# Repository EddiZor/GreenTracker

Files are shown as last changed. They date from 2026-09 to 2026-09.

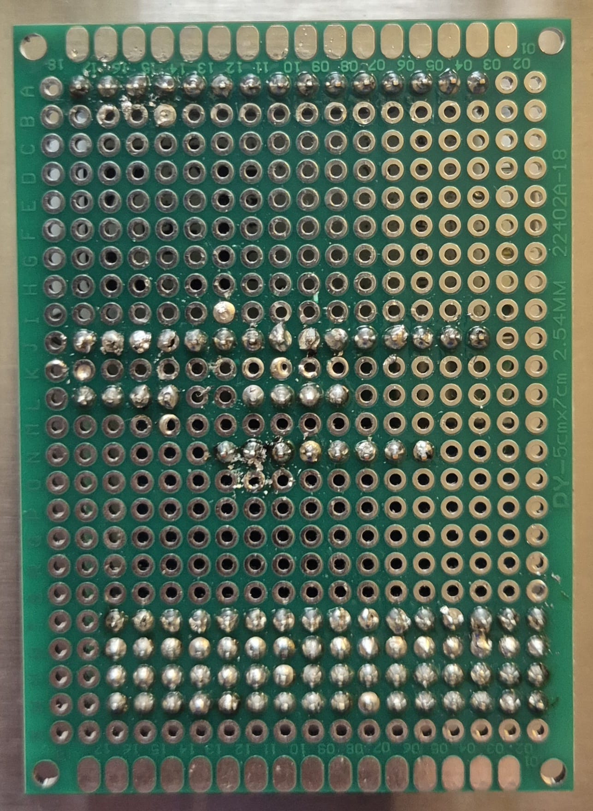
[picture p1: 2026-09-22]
images/002.jpeg

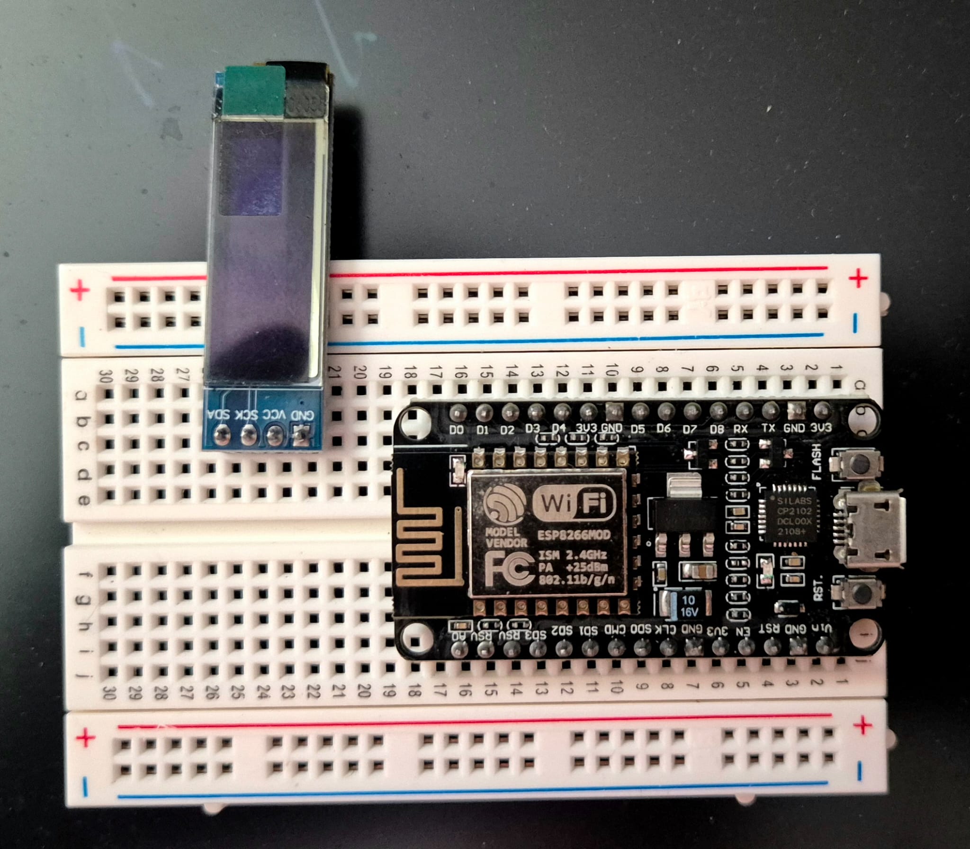
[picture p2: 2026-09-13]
WhatsApp Image 2026-09-13 at 14.21.58.jpeg

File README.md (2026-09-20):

# 🌿 GreenTracker v4.0

GreenTracker è un sistema IoT basato su ESP8266 (NodeMCU) progettato per monitorare l'umidità del suolo di un massimo di 16 piante contemporaneamente. 
La versione 4.0 trasforma il dispositivo in un server web autonomo, offrendo una dashboard in tempo reale accessibile da qualsiasi smartphone, oltre al rilevamento intelligente dei sensori e agli avvisi push.

## ✨ Novità della Versione 4.0
* **Web App Integrata:** Il NodeMCU genera nativamente una pagina web in HTML/CSS (Responsive & Dark Mode). Inserendo l'indirizzo IP del dispositivo nel browser dello smartphone, si ottiene una dashboard completa con i dati di tutti i sensori connessi.
* **Ritardo Intelligente (Smart Delay):** Creata una funzione dedicata (`attesaIntelligente`) per mantenere in ascolto il server web in background durante il carosello dei display OLED, azzerando i tempi di blocco.
* **Sistema Plug & Play:** Rileva automaticamente quali sensori sono fisicamente collegati ignorando le porte vuote e aggiornando dinamicamente i display e l'interfaccia web.
* **Notifiche Pushover:** Invia un alert push allo smartphone quando l'umidità di una specifica pianta scende sotto il 20% (con logica Anti-Spam integrata).

## 🛠️ Hardware Necessario
* 1x ESP8266 NodeMCU (ESP-12E)
* 1x Multiplexer Analogico 16 canali CD74HC4067 (Modello **HW-178**)
* 2x Display OLED 0.91" 128x32 (I2C)
* Fino a 16 Sensori di umidità del suolo capacitivi
* 2x Resistenze da 10 kOhm (da collegare in serie per ottenere 20 kOhm come pull-down)
* 1x Basetta Millefori 24x18

## 📖 Istruzioni di Assemblaggio
Per i dettagli su come saldare i componenti sulla millefori (ottimizzata per il modello HW-178) e la checklist dei collegamenti, consulta il file [ASSEMBLY.md](ASSEMBLY.md).

# 🌿 GreenTracker v3.0

GreenTracker è un sistema IoT basato su ESP8266 (NodeMCU) progettato per monitorare l'umidità del suolo di un massimo di 16 piante contemporaneamente. 
La versione 3.0 introduce il rilevamento intelligente dei sensori, avvisi push su smartphone e un layout hardware ottimizzato.

## ✨ Novità della Versione 3.0
* **Sistema Plug & Play:** Il sistema rileva automaticamente quali sensori sono fisicamente collegati (grazie a una resistenza di pull-down da 20kOhm) e ignora le porte vuote, aggiornando dinamicamente il carosello sui display OLED.
* **Notifiche Pushover:** Integrazione con l'API HTTPS di Pushover. Invia un alert sullo smartphone quando l'umidità di una specifica pianta scende sotto il 20%.
* **Logica Anti-Spam:** Il sistema memorizza lo stato degli allarmi inviati. Non invierà nuove notifiche per la stessa pianta finché l'umidità non tornerà sopra il 25%.
* **Self-Healing WiFi:** Inserita una routine di formattazione temporanea della memoria radio all'avvio per evitare conflitti di credenziali.

## 🛠️ Hardware Necessario
* 1x ESP8266 NodeMCU (ESP-12E)
* 1x Multiplexer Analogico 16 canali CD74HC4067 (Modello **HW-178**)
* 2x Display OLED 0.91" 128x32 (I2C)
* Fino a 16 Sensori di umidità del suolo capacitivi
* 1x Resistenza da 20 kOhm
* 1x Basetta Millefori 24x18

## 📖 Istruzioni di Assemblaggio
Per i dettagli su come saldare i componenti sulla millefori e la checklist dei collegamenti, consulta il file [ASSEMBLY.md](ASSEMBLY.md).

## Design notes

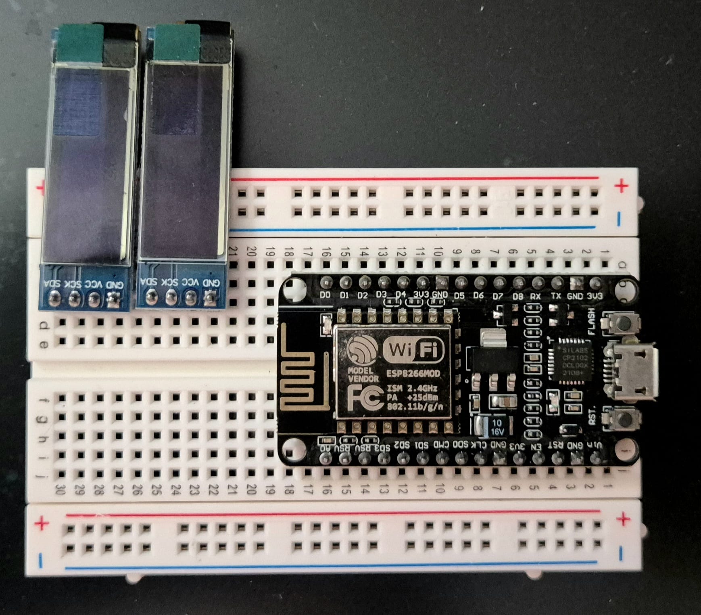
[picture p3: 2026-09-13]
WhatsApp Image 2026-09-13 at 14.21.58 b.jpeg

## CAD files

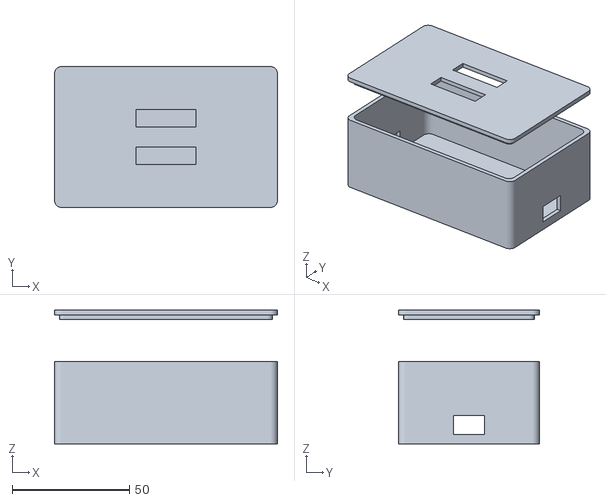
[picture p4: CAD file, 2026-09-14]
Case_3D/GreenTracker_Case.stl
95.0 x 60.0 x 57.0

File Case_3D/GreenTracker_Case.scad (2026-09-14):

// --- GreenTracker Case v1.0 ---

/* [Dimensioni Generali Scatola] */
lunghezza = 95;  // Spazio per NodeMCU e Multiplexer
larghezza = 60;
altezza = 35;
spessore_muro = 2;

/* [Tolleranze e Smussi] */
tolleranza_incastro = 0.4; // Tolleranza per la stampa 3D del coperchio
raggio_angoli = 3;         // Arrotondamento degli angoli esterni
$fn = 60;                  // Risoluzione curve

/* [Display OLED 0.91"] */
oled_finestra_l = 25.5; // Area visibile dello schermo
oled_finestra_h = 7.5;
distanza_tra_oled = 16; // Distanza dal centro di un display all'altro

/* [Connessioni] */
usb_l = 13;
usb_h = 8;
foro_cavi_l = 15;
foro_cavi_h = 8;

// --- MODULI BASE ---

module scatola_arrotondata(l, w, h, r) {
    hull() {
        translate([-l/2+r, -w/2+r, 0]) cylinder(r=r, h=h);
        translate([ l/2-r, -w/2+r, 0]) cylinder(r=r, h=h);
        translate([-l/2+r,  w/2-r, 0]) cylinder(r=r, h=h);
        translate([ l/2-r,  w/2-r, 0]) cylinder(r=r, h=h);
    }
}

module case_base() {
    difference() {
        // Corpo esterno
        scatola_arrotondata(lunghezza, larghezza, altezza, raggio_angoli);
        
        // Scavo interno
        translate([0, 0, spessore_muro])
            scatola_arrotondata(lunghezza - spessore_muro*2, larghezza - spessore_muro*2, altezza, raggio_angoli);
            
        // Foro USB (centrato su un lato corto)
        translate([lunghezza/2, 0, spessore_muro + usb_h/2 + 2])
            cube([spessore_muro*4, usb_l, usb_h], center=true);
            
        // Foro uscita cavi sensore/i (lato opposto)
        translate([-lunghezza/2, 0, spessore_muro + foro_cavi_h/2 + 2])
            cube([spessore_muro*4, foro_cavi_l, foro_cavi_h], center=true);
    }
}

module coperchio() {
    difference() {
        union() {
            // Piano del coperchio
            scatola_arrotondata(lunghezza, larghezza, spessore_muro, raggio_angoli);
            
            // Labbro di incastro interno
            translate([0, 0, -spessore_muro])
                scatola_arrotondata(
                    lunghezza - spessore_muro*2 - tolleranza_incastro, 
                    larghezza - spessore_muro*2 - tolleranza_incastro, 
                    spessore_muro, 
                    raggio_angoli - 1
                );
        }
        
        // Scavo per alleggerire il labbro interno
        translate([0, 0, -spessore_muro - 0.1])
            scatola_arrotondata(
                lunghezza - spessore_muro*4 - tolleranza_incastro, 
                larghezza - spessore_muro*4 - tolleranza_incastro, 
                spessore_muro + 0.2, 
                raggio_angoli - 2
            );

        // Finestra OLED 1 (Superiore) - Posizione Z corretta per trapassare il tetto
        translate([0, distanza_tra_oled/2, 0])
            cube([oled_finestra_l, oled_finestra_h, 20], center=true);
            
        // Finestra OLED 2 (Inferiore) - Posizione Z corretta per trapassare il tetto
        translate([0, -distanza_tra_oled/2, 0])
            cube([oled_finestra_l, oled_finestra_h, 20], center=true);
    }
}

// --- ASSEMBLAGGIO CON COLORI ---

// Base della scatola in grigio scuro
color([0.25, 0.25, 0.28]) 
    case_base();

// Coperchio in verde (sollevato di 20mm in vista esplosa)
color([0.2, 0.7, 0.3]) 
    translate([0, 0, altezza + 20]) 
        coperchio();

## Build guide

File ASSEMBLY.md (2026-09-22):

# 🛠️ Guida all'Assemblaggio GreenTracker

## 🗺️ Layout Millefori (Griglia 18x24 - Scala Reale 1:1)

Questo schema riproduce fedelmente la matrice di 18 colonne x 24 righe della scheda. Ogni simbolo rappresenta un singolo foro.
* `O` = Foro vuoto
* `N` = Pin del NodeMCU
* `[H]` = Connettori femmina (Header) per gli OLED
* `M` = Pin del Multiplexer (HW-178)
* `[S]`, `[V]`, `[G]` = Pettini inferiori Sensore, VCC, GND

```text
    1  2  3  4  5  6  7  8  9 10 11 12 13 14 15 16 17 18
  +----------------------------------------------------+
 1| O  N  N  N  N  N  N  N  N  N  N  N  N  N  N  N  O  O | <- NodeMCU (Top)
 2| O  |                                         |  O  O |
 3| O  |                                         |  O  O |
 4| O  |           N O D E   M C U               |  O  O |
 5| O  |          (USB a sinistra)               |  O  O |
 6| O  |                                         |  O  O |
 7| O  |                                         |  O  O |
 8| O  |                                         |  O  O |
 9| O  |                                         |  O  O |
10| O  N  N  N  N  N  N  N  N  N  N  N  N  N  N  N  O  O | <- NodeMCU (Bot)
11| O  O  O  O  O  O  O  O  O  O  O  O  O  O  O  O  O  O |
12| O  O  O  O  O [H][H][H][H] O [H][H][H][H] O  O  O  O | <- Prese OLED
13| O  O  O  O  O  O  O  O  O  O  O  O  O  O  O  O  O  O |
14| O  O  O  O  O  O  O  O  O  O  O  O  O  O  O  O  O  O |
15| O  O  O  O  O  M  M  M  M  M  M  M  M  O  O  O  O  O | <- MUX (Controllo)
16| O  O  O  O  O  |                    |  O  O  O  O  O |
17| O  O  O  O  O  |       HW-178       |  O  O  O  O  O |
18| O  O  O  O  O  |                    |  O  O  O  O  O |
19| O  O  O  O  O  |                    |  O  O  O  O  O |
20| O  M  M  M  M  M  M  M  M  M  M  M  M  M  M  M  M  O | <- MUX (Canali)
21| O  O  O  O  O  O  O  O  O  O  O  O  O  O  O  O  O  O |
22| O [S][S][S][S][S][S][S][S][S][S][S][S][S][S][S][S] O | <- 1. Pettine Segnali
23| O [V][V][V][V][V][V][V][V][V][V][V][V][V][V][V][V] O | <- 2. Pettine VCC 3.3V
24| O [G][G][G][G][G][G][G][G][G][G][G][G][G][G][G][G] O | <- 3. Pettine GND
  +----------------------------------------------------+
```

### 🪧 Legenda dei Pin (Da Sinistra a Destra)
* **NodeMCU Top (Riga 1):** A0, RSV, RSV, SD3, SD2, SD1, CMD, SD0, CLK, GND, 3V3, EN, RST, GND, Vin
* **NodeMCU Bot (Riga 10):** D0, D1, D2, D3, D4, 3V3, GND, D5, D6, D7, D8, RX, TX, GND, 3V3
* **MUX Controllo (Riga 15):** SIG, S3, S2, S1, S0, EN, VCC, GND
* **MUX Canali (Riga 20):** C15, C14, C13, C12, C11, C10, C9, C8, C7, C6, C5, C4, C3, C2, C1, C0

---

## 📋 Checklist Cablaggi e Saldature

**FASE 1: Blocco di Alimentazione (Pettini Inferiori)**
*Prepara le tre righe di pettini femmina sul fondo della scheda.*

- [ ] **Autostrada GND:** Unisci tutti i pin della riga inferiore (Riga 24) per creare il binario di Massa.
- [ ] Collega il binario GND a un pin **GND** del NodeMCU.
- [ ] Collega il binario GND al pin **GND** del Multiplexer (Riga 15, Colonna 13).
- [ ] Collega il binario GND al pin **EN** del Multiplexer (Riga 15, Colonna 11).
- [ ] Collega il binario GND ai due pin **GND** dei connettori OLED (es. ai secondi pin delle prese).
- [ ] **Autostrada VCC:** Unisci tutti i pin della riga centrale (Riga 23) per creare il binario 3.3V.
- [ ] Collega il binario VCC al pin **3V3** del NodeMCU.
- [ ] Collega il binario VCC al pin **VCC** del Multiplexer (Riga 15, Colonna 12).
- [ ] Collega il binario VCC ai due pin **VCC** dei connettori OLED.

**FASE 2: Cablaggi Display I2C (Prese Centrali sulla Riga 12)**
*Essendo i connettori posizionati perfettamente sotto i pin I2C del NodeMCU, le saldature saranno cortissime.*

- [ ] Connettore OLED 1 (SCL) -> Pin **D1** (NodeMCU, Colonna 3)
- [ ] Connettore OLED 1 (SDA) -> Pin **D2** (NodeMCU, Colonna 4)
- [ ] Connettore OLED 2 (SCL) -> Pin **D5** (NodeMCU, Colonna 9)
- [ ] Connettore OLED 2 (SDA) -> Pin **D6** (NodeMCU, Colonna 10)

**FASE 3: Logica Multiplexer e Plug & Play**
*Collega la fila da 8 pin del Multiplexer (Riga 15) ai rispettivi pin del NodeMCU.*

- [ ] Multiplexer **S0** (Col. 10) -> Pin **D3** (NodeMCU, Col. 5)
- [ ] Multiplexer **S1** (Col. 9) -> Pin **D4** (NodeMCU, Col. 6)
- [ ] Multiplexer **S2** (Col. 8) -> Pin **D7** (NodeMCU, Col. 11)
- [ ] Multiplexer **S3** (Col. 7) -> Pin **D8** (NodeMCU, Col. 12)
- [ ] Multiplexer **SIG** (Col. 6) -> Pin **A0** (NodeMCU, Col. 2 superiore)
- [ ] **Resistenza Plug & Play:** Salda DUE resistenze da 10k Ohm in serie (totale 20k Ohm) tra la pista di Segnale (A0 / SIG) e un punto connesso al **GND**.

**FASE 4: Segnali Sensori a Cascata (Righe 20-22)**
*Crea dei ponti verticali diritti di un paio di millimetri saltando la riga vuota (21), unendo i pin del Multiplexer (Riga 20) al pettine segnali sottostante (Riga 22).*

- [ ] Multiplexer **C15** -> Pettine Segnali Pin 1 (Estrema Sinistra, Colonna 2)
- [ ] Multiplexer da **C14** a **C1** -> Collega verticalmente ciascun pin al rispettivo foro sottostante (Colonne 3-16).
- [ ] Multiplexer **C0** -> Pettine Segnali Pin 16 (Estrema Destra, Colonna 17)

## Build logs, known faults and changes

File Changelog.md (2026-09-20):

### 4. File di Log delle Versioni (`CHANGELOG.md`)

```markdown
# Changelog
Tutte le modifiche rilevanti a questo progetto saranno documentate in questo file.

## [4.0.0] - 2026-09-20

### Aggiunto
- **Server Web Nativo:** Implementata la libreria `ESP8266WebServer` per ospitare una pagina HTML/CSS direttamente sulla memoria del NodeMCU.
- **Web App Dashboard:** Creata un'interfaccia utente responsive per smartphone (stile Dark Mode) che mostra in tempo reale i valori di umidità e segnala in rosso i sensori in allarme.
- **Supporto IP su Display:** Il secondo schermo OLED ora alterna la visualizzazione dello stato del WiFi con l'indirizzo IP locale, rendendo immediato l'accesso alla Web App.

### Modificato
- **Codifica Caratteri:** Aggiunto il tag `<meta charset='UTF-8'>` nell'HTML generato per interpretare correttamente gli emoji nei browser mobile.
- **Gestione del Timing:** Sostituiti i classici `delay()` nel loop principale con la nuova funzione custom `attesaIntelligente()`, che esegue un polling continuo di `server.handleClient()` garantendo l'assenza di lag durante la navigazione sulla Web App.

## [3.0.0] - 2026-09-19

### Aggiunto
- **Rilevamento Plug & Play:** Implementata logica per ignorare automaticamente le porte vuote del multiplexer.
- **Supporto Pushover:** Inserita libreria `ESP8266HTTPClient` per inviare notifiche push (HTTPS) allo smartphone.
- **Logica Anti-Spam:** Sistema di booleani per evitare invii ripetuti di allarmi sotto la soglia critica del 20%.
- **Layout Hardware HW-178:** Creata una mappatura dedicata per la basetta millefori 24x18.
- **Checklist Saldature:** Aggiunto un tracker in Markdown nel file ASSEMBLY.md.

### Modificato
- **Routine di connessione WiFi:** Aggiunto blocco `WiFi.mode(WIFI_STA); WiFi.disconnect();` nel setup per forzare il reset della memoria radio ed evitare loop di connessione.

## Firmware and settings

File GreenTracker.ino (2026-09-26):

/**
 * Progetto: GreenTracker
 * Versione: 5.1 (Fixed Serial Boot & Pushover HTTP)
 * Autore: SKYSIM PILOT
 */

#include <Arduino.h>
#include <U8g2lib.h>
#include <Wire.h>
#include <ESP8266WiFi.h>
#include <ESP8266HTTPClient.h>
#include <ESP8266WebServer.h>
#include <time.h> // Libreria per l'orario

// --- Credenziali WiFi ---
const char* ssid = "IL_TUO_WIFI";       
const char* password = "LA_TUA_PASSWORD";   

// --- Credenziali Pushover ---
const char* pushoverApiToken = "INSERISCI_QUI_IL_TOKEN_APP";
const char* pushoverUserKey = "INSERISCI_QUI_IL_USER_KEY";

ESP8266WebServer server(80);

const int pin_S0 = D3;
const int pin_S1 = D4;
const int pin_S2 = D7;
const int pin_S3 = D8;
const int pin_SIG = A0;

const int MAX_SENSORI = 16; 
int valoriSensori[16]; 
bool sensoreConnesso[16]; 
bool allarmeInviato[16]; 

const int valoreAriaSecca = 850; 
const int valoreAcqua = 350;

U8G2_SSD1306_128X32_UNIVISION_F_SW_I2C display1(U8G2_R0, D1, D2, U8X8_PIN_NONE);
U8G2_SSD1306_128X32_UNIVISION_F_SW_I2C display2(U8G2_R0, D5, D6, U8X8_PIN_NONE);

void attesaIntelligente(unsigned long ms) {
  unsigned long inizio = millis();
  while (millis() - inizio < ms) {
    server.handleClient(); 
    delay(10);
  }
}

int leggiCanaleMux(int canale) {
  digitalWrite(pin_S0, bitRead(canale, 0));
  digitalWrite(pin_S1, bitRead(canale, 1));
  digitalWrite(pin_S2, bitRead(canale, 2));
  digitalWrite(pin_S3, bitRead(canale, 3));
  delay(10); 
  return analogRead(pin_SIG);
}

// --- FUNZIONE: Genera la pagina HTML della Web App ---
void gestisciPaginaPrincipale() {
  time_t now = time(nullptr);
  struct tm* timeinfo = localtime(&now);
  String orarioAggiornamento = "Sincronizzazione in corso...";
  if (timeinfo->tm_year > 120) { 
    char timeString[10];
    sprintf(timeString, "%02d:%02d:%02d", timeinfo->tm_hour, timeinfo->tm_min, timeinfo->tm_sec);
    orarioAggiornamento = String(timeString);
  }

  String html = "<!DOCTYPE html><html><head>";
  html += "<meta charset='UTF-8'>";
  html += "<meta name='viewport' content='width=device-width, initial-scale=1.0, user-scalable=no'>";
  html += "<meta name='apple-mobile-web-app-capable' content='yes'>";
  html += "<meta http-equiv='refresh' content='30'>"; // AUTO-REFRESH ogni 30 secondi
  html += "<title>GreenTracker Live</title>";
  html += "<style>";
  html += "body { font-family: 'Segoe UI', sans-serif; background-color: #121212; color: #fff; margin: 0; padding: 15px; text-align: center; }";
  html += "h1 { color: #4CAF50; font-size: 1.8em; margin-bottom: 10px; }";
  html += ".card { background-color: #1e1e1e; border-radius: 10px; padding: 15px; margin: 15px auto; max-width: 400px; box-shadow: 0 4px 8px rgba(0,0,0,0.4); text-align: left; }";
  html += ".card-header { display: flex; justify-content: space-between; align-items: center; margin-bottom: 8px; }";
  html += ".card-title { font-size: 1.1em; font-weight: bold; color: #eee; }";
  html += ".card-value { font-size: 1.3em; font-weight: bold; }";
  html += ".progress-bg { background-color: #333; border-radius: 5px; height: 10px; width: 100%; overflow: hidden; }";
  html += ".progress-bar { height: 100%; border-radius: 5px; transition: width 0.5s; }";
  html += ".bg-green { background-color: #4CAF50; color: #4CAF50; }";
  html += ".bg-yellow { background-color: #FFC107; color: #FFC107; }";
  html += ".bg-red { background-color: #F44336; color: #F44336; }";
  html += ".card-luce { border-left: 4px solid #FFC107; }";
  html += ".card-pianta { border-left: 4px solid #4CAF50; }";
  html += ".footer { color: #888; font-size: 0.85em; margin-top: 30px; line-height: 1.5; }";
  html += "</style></head><body>";
  
  html += "<h1>🌿 GreenTracker</h1>";
  
  bool almenoUnSensore = false;
  
  for (int i = 0; i < 15; i++) {
    if (sensoreConnesso[i]) {
      almenoUnSensore = true;
      int umidita = valoriSensori[i];
      
      String coloreClasse = "bg-green";
      if (umidita <= 20) coloreClasse = "bg-red";
      else if (umidita <= 40) coloreClasse = "bg-yellow";
      
      html += "<div class='card card-pianta'>";
      html += "<div class='card-header'>";
      html += "<span class='card-title'>🌱 Sensore " + String(i + 1) + " (C" + String(i) + ")</span>";
      html += "<span class='card-value " + coloreClasse + "'>" + String(umidita) + "%</span>";
      html += "</div>";
      html += "<div class='progress-bg'><div class='progress-bar " + coloreClasse + "' style='width: " + String(umidita) + "%;'></div></div>";
      html += "</div>";
    }
  }

  if (sensoreConnesso[15]) {
      almenoUnSensore = true;
      int luce = valoriSensori[15];
      html += "<div class='card card-luce'>";
      html += "<div class='card-header'>";
      html += "<span class='card-title'>☀️ Esposizione Luce</span>";
      html += "<span class='card-value bg-yellow'>" + String(luce) + "%</span>";
      html += "</div>";
      html += "<div class='progress-bg'><div class='progress-bar bg-yellow' style='width: " + String(luce) + "%;'></div></div>";
      html += "</div>";
  }
  
  if (!almenoUnSensore) {
    html += "<p style='color: #aaa; margin-top:30px;'>Nessun sensore rilevato.</p>";
  }
  
  html += "<div class='footer'>Ultimo aggiornamento: <b>" + orarioAggiornamento + "</b><br>Rete WiFi: " + String(ssid) + "</div>";
  html += "</body></html>";
  
  server.send(200, "text/html", html);
}

String urlEncode(String str) {
  String encodedString = "";
  char c;
  char code0;
  char code1;
  for (int i = 0; i < str.length(); i++){
    c = str.charAt(i);
    if (c == ' '){
      encodedString += '+';
    } else if (isalnum(c)){
      encodedString += c;
    } else{
      code1 = (c & 0xf) + '0';
      if ((c & 0xf) > 9){
          code1 = (c & 0xf) - 10 + 'A';
      }
      c = (c >> 4) & 0xf;
      code0 = c + '0';
      if (c > 9){
          code0 = c - 10 + 'A';
      }
      encodedString += '%';
      encodedString += code0;
      encodedString += code1;
    }
  }
  return encodedString;
}

// --- FUNZIONE PUSHOVER (HTTP Standard) ---
void inviaNotificaPushover(String messaggio) {
  if (WiFi.status() != WL_CONNECTED) return;
  
  Serial.println("\n[Pushover] Preparazione invio notifica...");
  
  WiFiClient client; // Client standard non sicuro
  HTTPClient http;
  
  http.begin(client, "http://api.pushover.net/1/messages.json");
  http.addHeader("Content-Type", "application/x-www-form-urlencoded");
  
  String postData = "token=" + String(pushoverApiToken) + "&user=" + String(pushoverUserKey) + "&message=" + urlEncode(messaggio);
  
  int httpResponseCode = http.POST(postData);
  
  Serial.print("[Pushover] Codice HTTP di risposta: ");
  Serial.println(httpResponseCode);
  
  if (httpResponseCode > 0) {
    String response = http.getString();
    Serial.println("[Pushover] Risposta del server: " + response);
  } else {
    Serial.println("[Pushover] ERRORE: Connessione fallita. Codice: " + String(httpResponseCode));
  }
  
  http.end();
}

void setup() {
  Serial.begin(115200);
  delay(2000); // Stabilizzazione seriale post-boot
  Serial.println("\n\n[GreenTracker] Avvio in corso...");

  pinMode(pin_S0, OUTPUT);
  pinMode(pin_S1, OUTPUT);
  pinMode(pin_S2, OUTPUT);
  pinMode(pin_S3, OUTPUT);
  pinMode(pin_SIG, INPUT);

  for(int i = 0; i < MAX_SENSORI; i++) {
    allarmeInviato[i] = false;
  }

  display1.begin();
  display2.begin();

  display2.clearBuffer();
  display2.setFont(u8g2_font_helvB12_tr);
  display2.drawStr(0, 13, "GreenTracker");
  display2.drawStr(0, 31, "Connessione...");
  display2.sendBuffer();

  WiFi.mode(WIFI_STA); 
  WiFi.disconnect();   
  delay(100);          
  WiFi.begin(ssid, password);
  
  // Ciclo di connessione WiFi con timeout protetto
  int tentativi = 0;
  while (WiFi.status() != WL_CONNECTED) { 
    delay(500); 
    Serial.print(".");
    tentativi++;
    if (tentativi > 30) {
      Serial.println("\n[WiFi] Connessione fallita! Verifica SSID e Password.");
      break; 
    }
  }
  
  Serial.println("\n[WiFi] Connesso! Indirizzo IP: " + WiFi.localIP().toString());
  
  configTime("CET-1CEST,M3.5.0,M10.5.0/3", "pool.ntp.org");
  
  server.on("/", gestisciPaginaPrincipale); 
  server.begin();
  
  display2.clearBuffer();
  display2.drawStr(0, 13, "WiFi: Connesso!");
  display2.sendBuffer();
  
  display1.clearBuffer();
  display1.setFont(u8g2_font_helvB12_tr);
  display1.drawStr(0, 13, "Sistema OK");
  display1.sendBuffer();

  // ---> AGGIUNGI QUESTA RIGA PER RICEVERE LA NOTIFICA ALL'ACCENSIONE <---
  inviaNotificaPushover("🌿 GreenTracker avviato e online!");

  attesaIntelligente(3000); 
}

void loop() {
  server.handleClient(); 

  for (int i = 0; i < MAX_SENSORI; i++) {
    int valoreGrezzo = leggiCanaleMux(i);
    if (valoreGrezzo < 50) {
      sensoreConnesso[i] = false;
      allarmeInviato[i] = false; 
    } else {
      sensoreConnesso[i] = true;
      
      if (i == 15) { 
        int perc = map(valoreGrezzo, 0, 1023, 0, 100);
        valoriSensori[i] = constrain(perc, 0, 100);
      } else {
        int perc = map(valoreGrezzo, valoreAriaSecca, valoreAcqua, 0, 100);
        valoriSensori[i] = constrain(perc, 0, 100);

        if (valoriSensori[i] < 20) {
          if (!allarmeInviato[i]) {
            String msg = "💧 Sensore " + String(i + 1) + " ha sete! Umidità: " + String(valoriSensori[i]) + "%";
            inviaNotificaPushover(msg);
            allarmeInviato[i] = true; 
          }
        } else if (valoriSensori[i] > 25) {
          allarmeInviato[i] = false;
        }
      }
    }
  }

  bool almenoUnSensore = false;

  for (int i = 0; i < MAX_SENSORI; i++) {
    if (!sensoreConnesso[i]) continue; 
    almenoUnSensore = true; 

    display1.clearBuffer();
    display1.setFont(u8g2_font_helvB12_tr); 
    
    if (i == 15) {
      display1.drawStr(0, 13, "Sensore Luce"); 
      display1.drawStr(0, 31, "Esposiz.:");
    } else {
      display1.drawStr(0, 13, ("Sensore " + String(i + 1)).c_str()); 
      display1.drawStr(0, 31, "Umidita':"); 
    }
      
    display1.setFont(u8g2_font_helvB14_tr); 
    String percTesto = String(valoriSensori[i]) + "%";
    display1.setCursor(128 - display1.getStrWidth(percTesto.c_str()), 31); 
    display1.print(percTesto);
    display1.sendBuffer(); 

    display2.clearBuffer();
    display2.setFont(u8g2_font_helvB10_tr); 
    display2.drawStr(0, 13, WiFi.localIP().toString().c_str());
    
    time_t now = time(nullptr);
    struct tm* timeinfo = localtime(&now);
    if (timeinfo->tm_year > 120) {
      char timeStr[10];
      sprintf(timeStr, "%02d:%02d", timeinfo->tm_hour, timeinfo->tm_min);
      display2.setFont(u8g2_font_helvB12_tr);
      display2.drawStr(0, 31, timeStr); 
    } else {
      display2.drawStr(0, 31, "WiFi: OK"); 
    }
    display2.sendBuffer(); 

    attesaIntelligente(3000); 
  }

  if (!almenoUnSensore) {
    display1.clearBuffer();
    display1.setFont(u8g2_font_helvB12_tr);
    display1.drawStr(0, 13, "Nessun sensore");
    display1.sendBuffer();
    attesaIntelligente(2000);
  }
}

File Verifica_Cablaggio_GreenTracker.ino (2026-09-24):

#include <Arduino.h>
#include <Wire.h>
#include <U8g2lib.h>

// Definizione Pin Multiplexer
const int pin_S0 = D3;
const int pin_S1 = D4;
const int pin_S2 = D7;
const int pin_S3 = D8;
const int pin_SIG = A0;

// Configurazione Display (SCK, SDA)
U8G2_SSD1306_128X32_UNIVISION_F_SW_I2C display1(U8G2_R0, D1, D2, U8X8_PIN_NONE);
U8G2_SSD1306_128X32_UNIVISION_F_SW_I2C display2(U8G2_R0, D5, D6, U8X8_PIN_NONE);

// Funzione Scanner I2C
void scansionaBusI2C(int pinSDA, int pinSCL, String nomePorta) {
  Serial.print("🔍 Controllo cablaggi su ");
  Serial.print(nomePorta);
  Serial.println("...");

  Wire.begin(pinSDA, pinSCL);
  byte errore, indirizzo;
  int dispositiviTrovati = 0;

  for(indirizzo = 1; indirizzo < 127; indirizzo++ ) {
    Wire.beginTransmission(indirizzo);
    errore = Wire.endTransmission();
    
    if (errore == 0) {
      Serial.print("   ✅ TROVATO DISPLAY all'indirizzo: 0x");
      if (indirizzo < 16) Serial.print("0");
      Serial.println(indirizzo, HEX);
      dispositiviTrovati++;
    } 
  }
  
  if (dispositiviTrovati == 0) {
    Serial.println("   ❌ NESSUN DISPOSITIVO TROVATO. Controllare i cavi.");
  }
  Serial.println("-----------------------------------");
}

void setup() {
  Serial.begin(115200);
  delay(2000); // Attesa per aprire il monitor seriale
  
  Serial.println("\n\n🛠️ INIZIO TEST HARDWARE GREENTRACKER 🛠️\n");

  // TEST 1: Scansione elettrica delle piste I2C
  scansionaBusI2C(D2, D1, "PRESA OLED 1 (Pin D1/D2)"); // SDA=D2, SCK=D1
  scansionaBusI2C(D6, D5, "PRESA OLED 2 (Pin D5/D6)"); // SDA=D6, SCK=D5

  // TEST 2: Accensione Display
  Serial.println("Accensione Display 1...");
  display1.begin();
  display1.clearBuffer();
  display1.setFont(u8g2_font_helvB12_tr);
  display1.drawStr(5, 20, "OLED 1: TEST OK");
  display1.sendBuffer();

  Serial.println("Accensione Display 2...");
  display2.begin();
  display2.clearBuffer();
  display2.setFont(u8g2_font_helvB12_tr);
  display2.drawStr(5, 20, "OLED 2: TEST OK");
  display2.sendBuffer();

  // Configurazione Pin Multiplexer per il loop
  pinMode(pin_S0, OUTPUT);
  pinMode(pin_S1, OUTPUT);
  pinMode(pin_S2, OUTPUT);
  pinMode(pin_S3, OUTPUT);
  pinMode(pin_SIG, INPUT);
}

void loop() {
  Serial.println("\n📡 Lettura in tempo reale dei canali Multiplexer:");
  
  for (int i = 0; i < 16; i++) {
    digitalWrite(pin_S0, bitRead(i, 0));
    digitalWrite(pin_S1, bitRead(i, 1));
    digitalWrite(pin_S2, bitRead(i, 2));
    digitalWrite(pin_S3, bitRead(i, 3));
    delay(10);
    int valore = analogRead(pin_SIG);

    Serial.print("   C");
    if (i < 10) Serial.print("0");
    Serial.print(i);
    Serial.print(": \t[");
    Serial.print(valore);
    Serial.println("]");
  }
  
  delay(5000); // Ripete la lettura ogni 5 secondi
}

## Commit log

2026-09-12 Initial commit: firmware per monitor capacitivo OLED
2026-09-12 Aggiunto .gitignore per pulire il repository
2026-09-14 Aggiunto modello parametrico del case in OpenSCAD e file STL
    [GreenTracker_Case.scad, GreenTracker_Case.stl]
2026-09-19 assemblaggio e disposizione componeneti
2026-09-21 Fix formatting in assembly layout for clarity
2026-09-22 Update assembly guide for GreenTracker: clarify NodeMCU orientation and enhance layout description
2026-09-22 Fix formatting in assembly layout for OLED and NodeMCU sections
2026-09-22 Fix formatting in assembly layout for improved clarity
2026-09-22 Update GreenTracker to version 5.0: enhance live dashboard features, improve sensor handling, and refine HTML layout
2026-09-22 Fix display labels for sensor readings in the loop function
    [GreenTracker.ino]
2026-09-22 Update assembly guide for GreenTracker: refine layout and clarify pin connections for NodeMCU and multiplexer
2026-09-22 Refactor code structure for improved readability and maintainability and added board images
2026-09-24 Add initial implementation of GreenTracker hardware test with I2C scanning and OLED display setup
